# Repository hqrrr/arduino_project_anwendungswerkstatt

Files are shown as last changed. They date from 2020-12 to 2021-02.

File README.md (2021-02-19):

# Anwendungswerkstatt project climate chair 
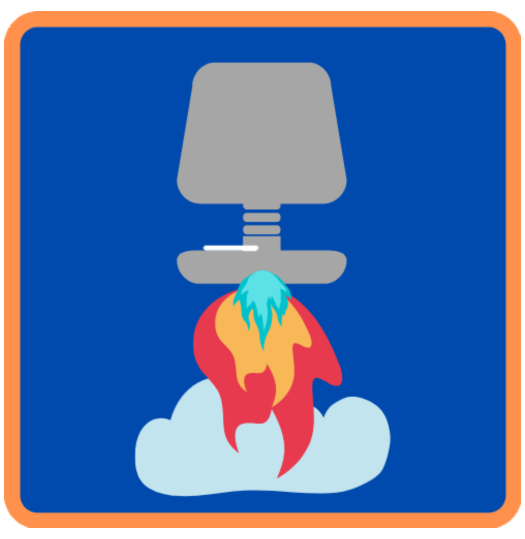
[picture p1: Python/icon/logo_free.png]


## Table of contents
1. [Diagram](#diagram)
    
    1.1 [Draft](#draft)
   
    1.2 [Circuit diagram](#circuit-diagram)

    1.3 [Sketch](#sketch)

2. [Python code](#python-code)

3. [Arduino code](#arduino-code)

    3.1 [Arduino desk (Primary)](#primary)

    3.2 [Arduino chair (Replica)](#replica)
   
4. [List of hardware](#hardware)

## 1 Diagram 

### 1.1 Draft 

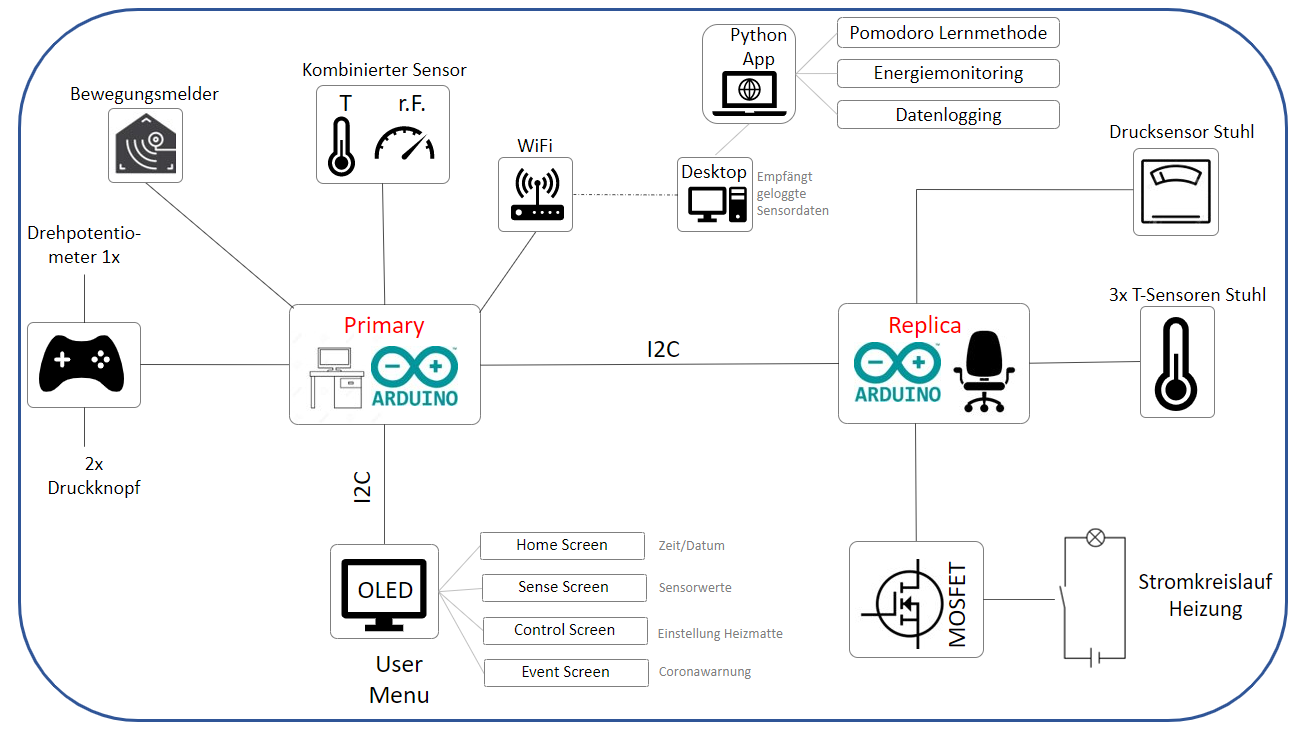
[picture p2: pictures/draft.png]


### 1.2 Circuit diagram 

#### 1.2.1 Arduino Desk (Primary) {Arduino MKR WiFi 1010}

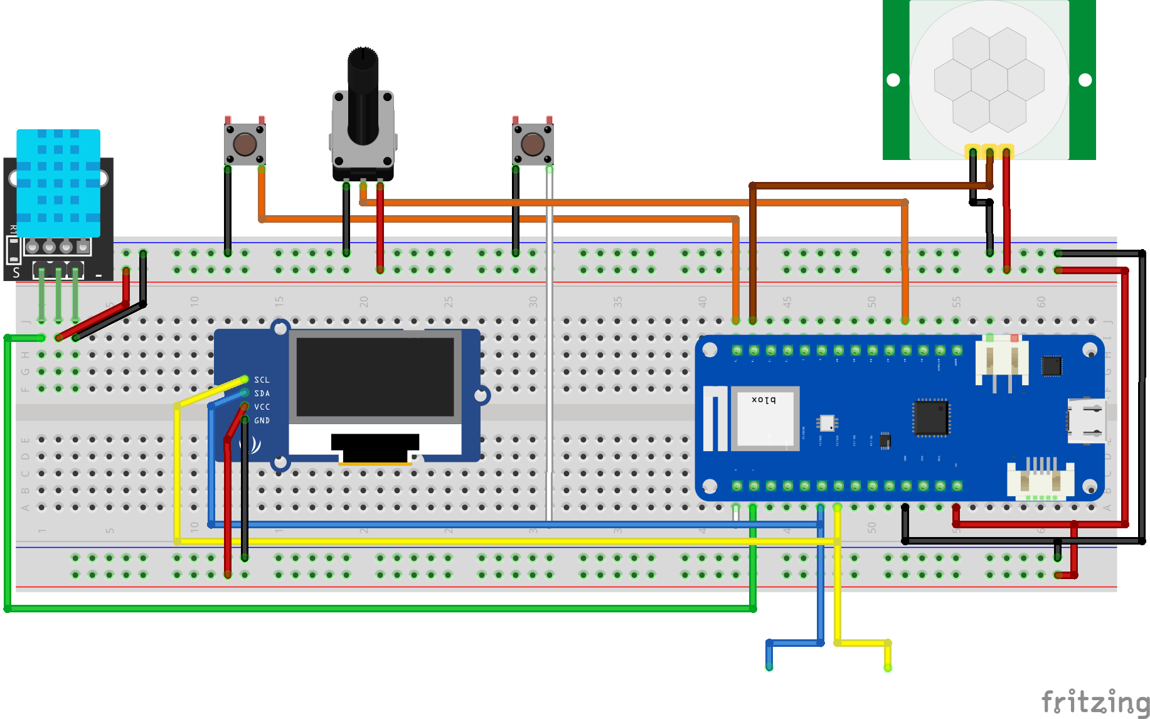
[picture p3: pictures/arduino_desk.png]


#### 1.2.2 Arduino Chair (Replica) {Arduino Nano ATmega328P (Old Bootloader)}

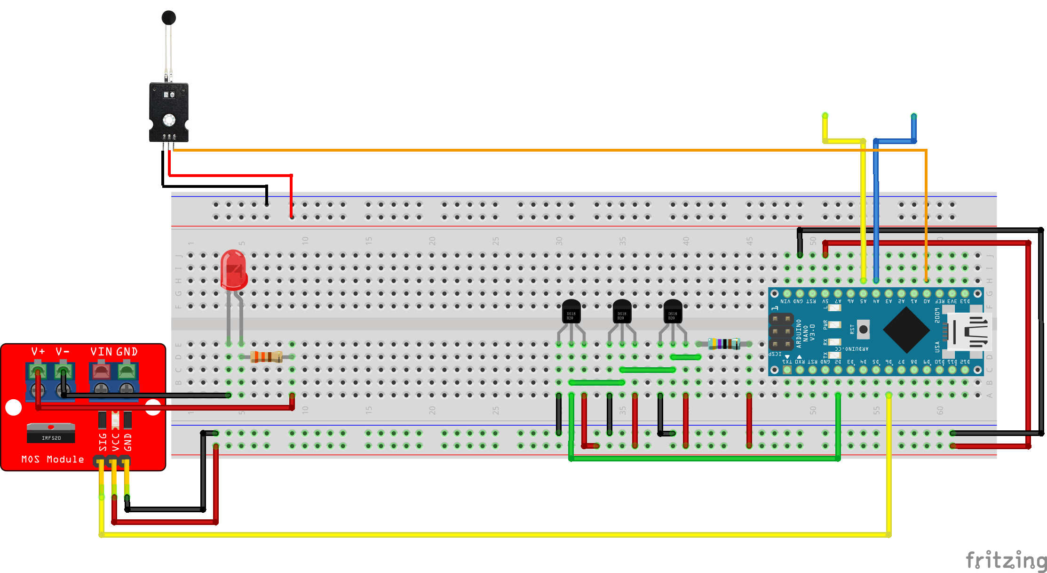
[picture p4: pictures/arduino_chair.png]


### 1.3 Sketch 

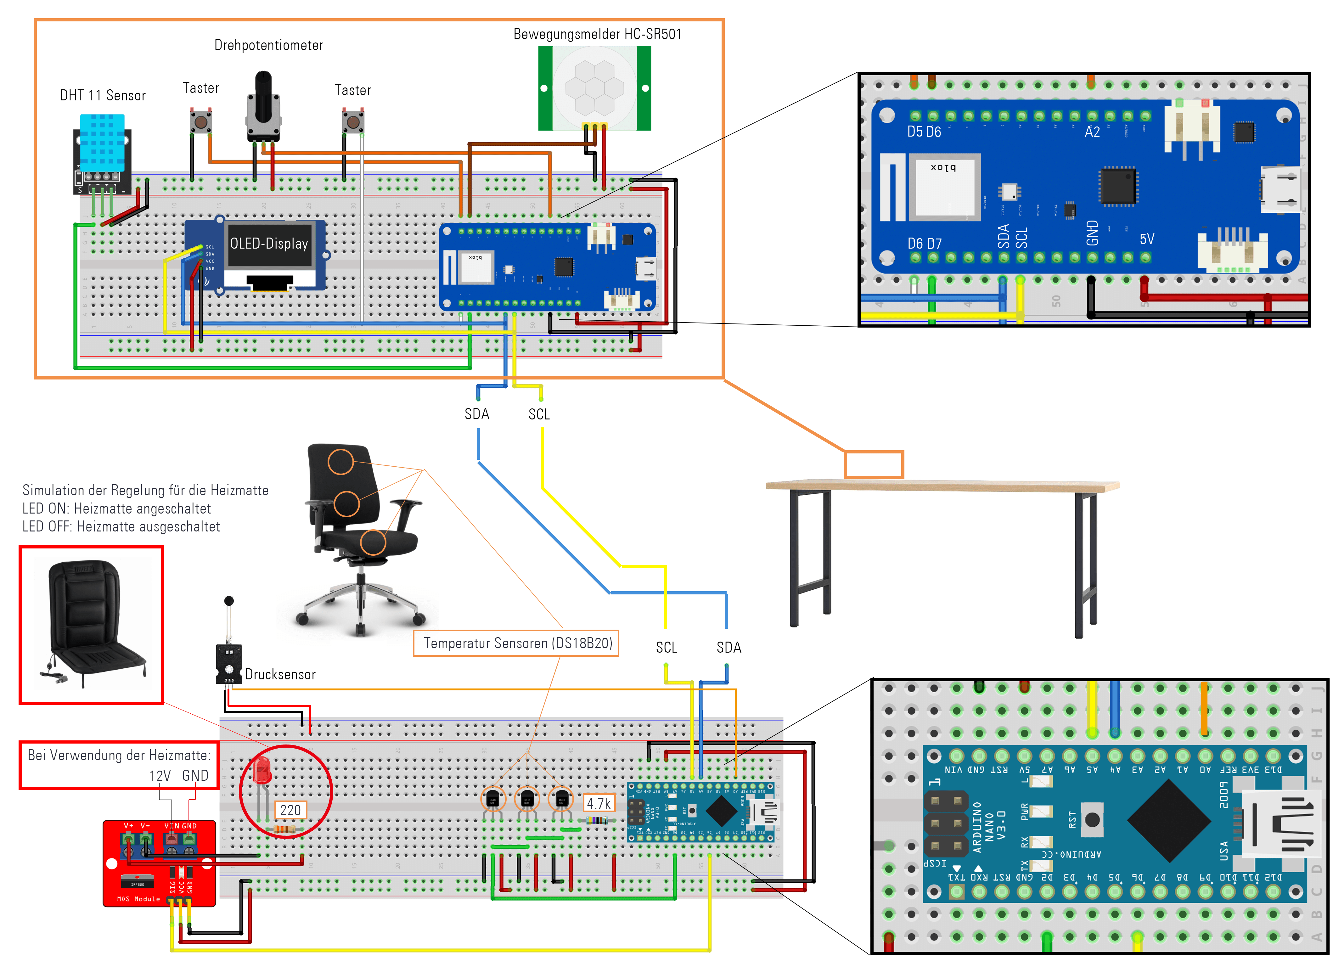
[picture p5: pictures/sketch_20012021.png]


## 2. python code 

[desktop_file.py](/Python/desktop_file.py)

settings:

[desktop.ini](/Python/desktop.ini)

Environmental:

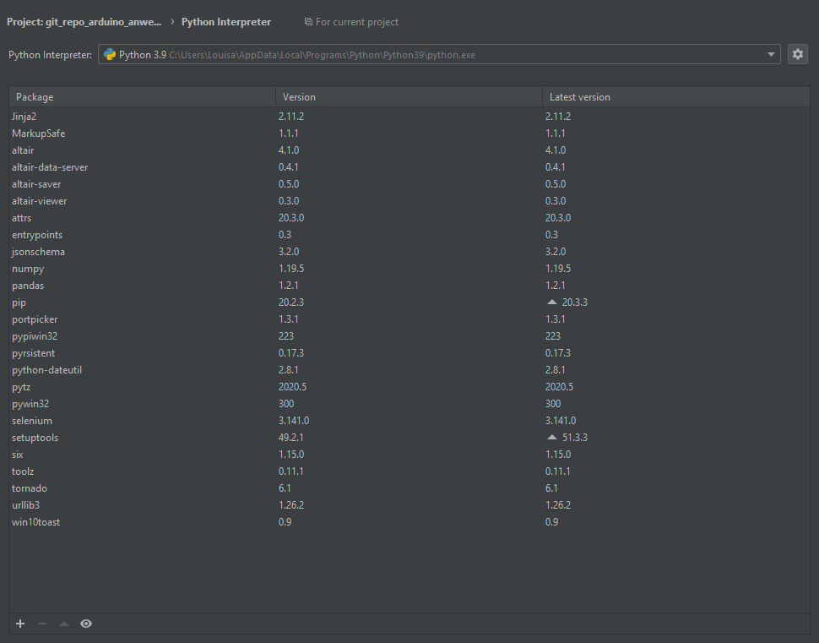
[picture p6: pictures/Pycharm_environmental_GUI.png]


## 3. Arduino code: 

### 3.1 Arduino Desk (Primary) {Arduino MKR WiFi 1010} 

[Arduino_Desk_Primary_mkr_wifi_1010.ino](/Arduino/Arduino_Desk_Primary_mkr_wifi_1010/Arduino_Desk_Primary_mkr_wifi_1010.ino)

Change WiFi username & password in:

[arduino_secrets.h](/Arduino/Arduino_Desk_Primary_mkr_wifi_1010/arduino_secrets.h)

Circuit diagram --> **1.2.1**

### 3.2 Arduino Chair (Replica) {Arduino Nano ATmega328P (Old Bootloader)} 

[Arduino_Chair_Replica_Nano.ino](/Arduino/Arduino_Chair_Replica_Nano/Arduino_Chair_Replica_Nano.ino)

Circuit diagram --> **1.2.2**

## 4. list of hardware: 

| components | name | description | Library / Software |
| --- | --- | --- | --- |
| microcontroller | Arduino Nano | ATmega 328P (old bootloader), Arduino chair. Controls sensors and actuators. | Arduino IDE |
| microcontroller with WiFi | Arduino MKR WiFi 1010 | Controls sensors and actuators. Opens servers and sends data via WiFi | Arduino IDE, WiFiNINA.h(Library), SPI.h (Library)  |
| real Time Clock | integrated in Arduino MKR WiFi 1010 | Time measurement, time update via WiFi | RTCZero.h (Library) |
| temperature and humidity sensor | DHT 11 | Measures temperature and humidity, transmits data digitally | DHT.h (Library) |
| motion sensor | HC-SR501 | passive infrared sensor | - |
| 2x button | - | An electrical connection is established by pressing a button | - |
| rotary potentiometer | - | Allows manual setting of a resistance in 1024 levels | - |
| OLED display  | SSD1306  | Display with 128 x 64 pixels, to be operated via I2C bus | Adafruit_SSD1306.h, Wire.h, Adafruit_GFX.h(Libraries)  |
| 2x Breadboard | - | - | - |
| 3x temperatur sensors | DS18B20 | A 4.7k resistor is required, see circuit diagram | OneWire.h (Library), DallasTemperature.h (Library) |
| pressure sensor | ARD SEN-PRESSURE10 | - | - |
| MOSFET | Grove MOSFET CJQ4435 | - | - |
| Heating mat | Car seat heating pad with 2 levels (12 V) | - | - |

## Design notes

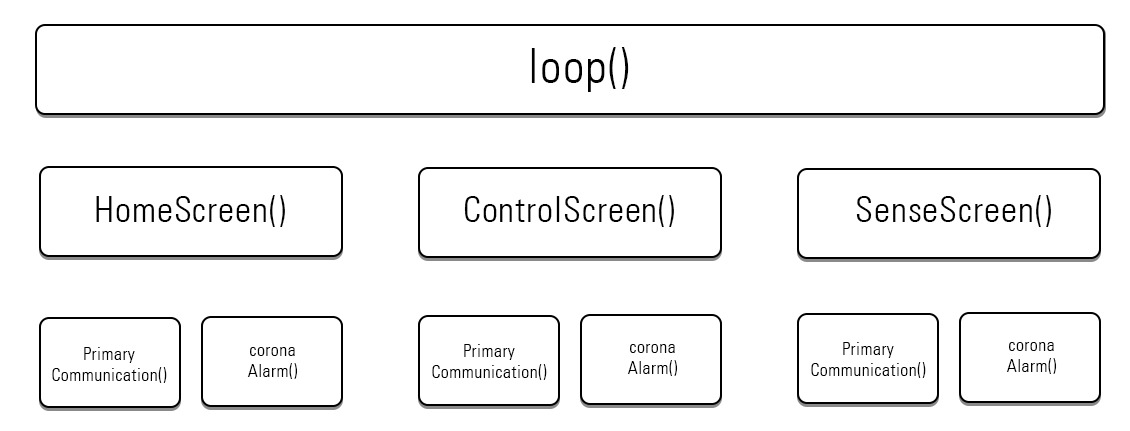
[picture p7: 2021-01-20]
pictures/structure.png

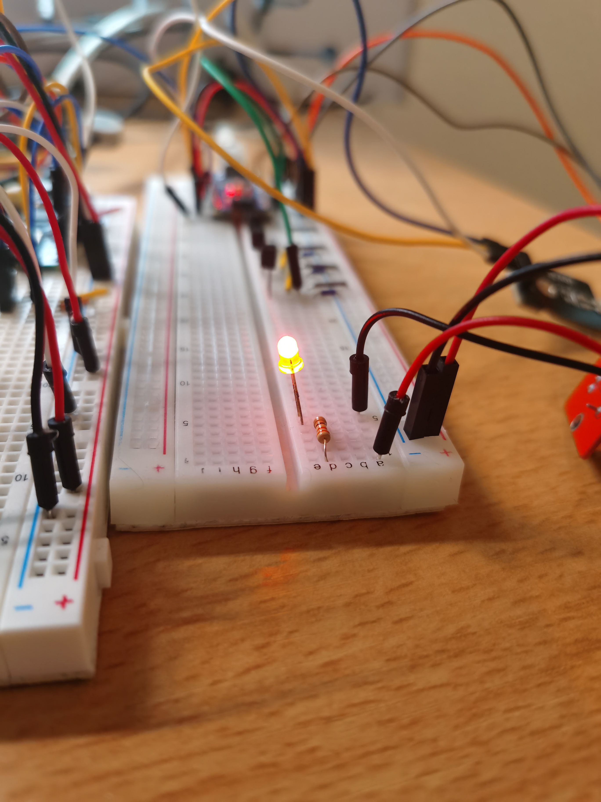
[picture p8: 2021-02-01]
pictures/LED_on.jpg

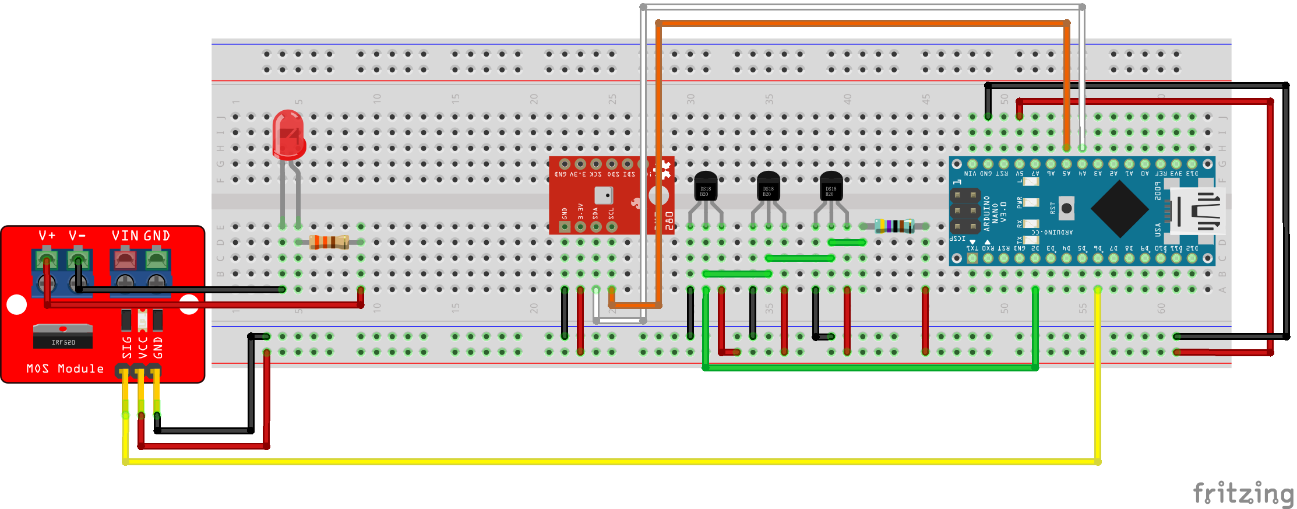
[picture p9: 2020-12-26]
pictures/arduino_dallas_bme280_mosfet.png

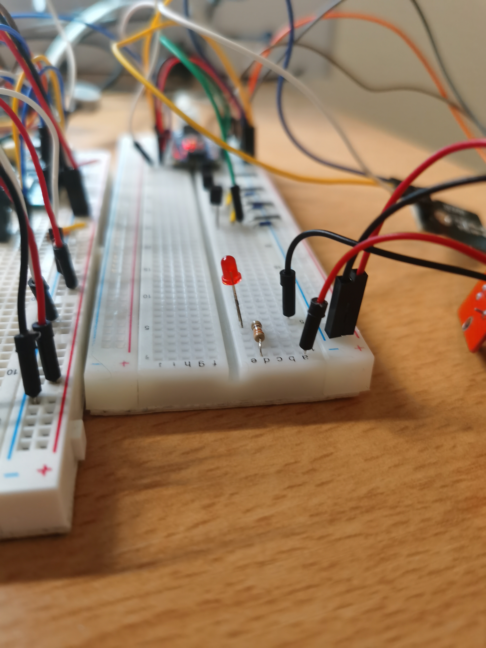
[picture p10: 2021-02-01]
pictures/LED_off.jpg

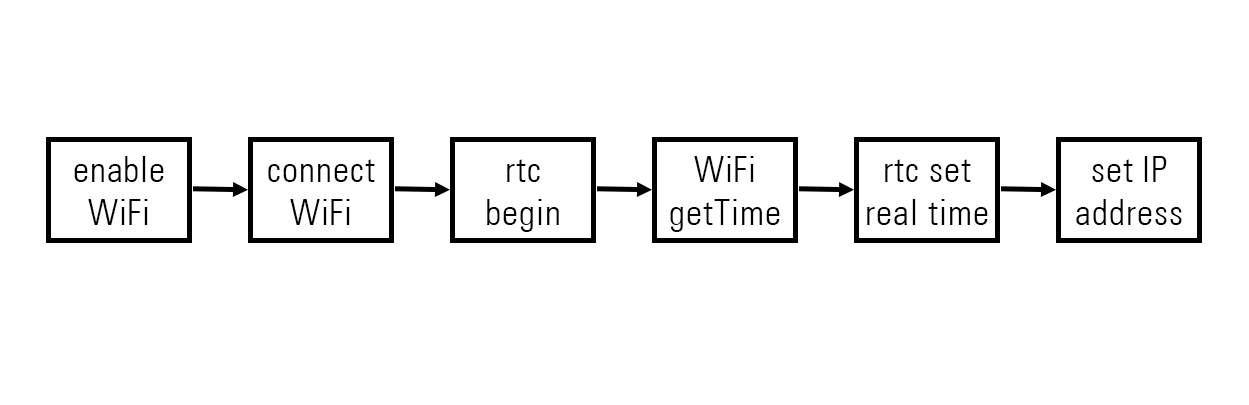
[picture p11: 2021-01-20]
pictures/process_get_time.png

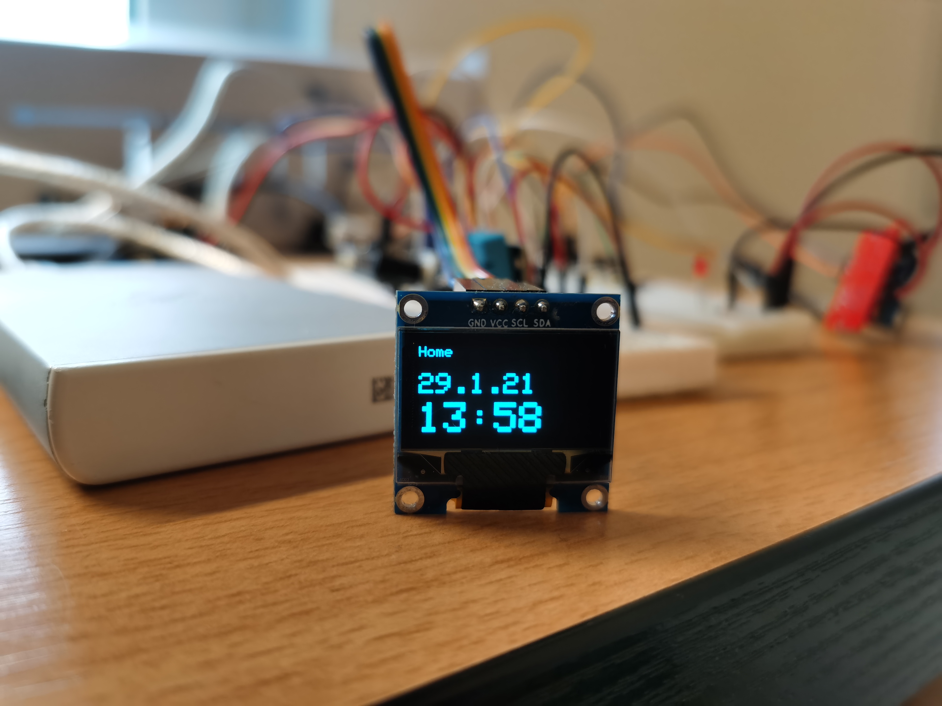
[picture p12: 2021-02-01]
pictures/homescreen.jpg

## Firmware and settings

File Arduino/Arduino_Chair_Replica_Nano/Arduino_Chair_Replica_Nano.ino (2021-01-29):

// =================================
// Arduino Nano
// Arduino 1.8.13
// Author: hqrrr
// Date of last update: Jan. 2021
// =================================

// ---------------------------
//     I2C communication
// ---------------------------
#include<Wire.h>

// ---------------------------
//  Dallas Temperature sensor
// ---------------------------
#include <OneWire.h> 
#include <DallasTemperature.h>

// Data wire is plugged into pin 2 on the Arduino 
#define ONE_WIRE_BUS 2 

// Setup a oneWire instance to communicate with any OneWire devices  
// (not just Maxim/Dallas temperature ICs) 
OneWire oneWire(ONE_WIRE_BUS); 

// Pass our oneWire reference to Dallas Temperature. 
DallasTemperature sensors(&oneWire);


// ---------------------------
//     PID controller
// ---------------------------
/*
 * by Dorian
 * Concept:
 * 1) We read the temperature (Input) in the center of the chair
 * 2) We compare the Input with Setpoint and compute Output (heaterPID.Compute())
 * 3) We translate output into Power with upper and lower limit (0-100%)
 * 4) We translate Power into a pulse to control the heater
 *
 * Reglerparameter: Kp, Ki, Kd, delay zwischen Messungen
 * (je kürzer das delay, desto schneller wächst der Integratoranteil im Regler)
 */
#include <PID_v1.h>
// PI controller
double Setpoint;  // T_set
double Input;     // T_room
double Output;    // Power
double Kp = 1, Ki = 1, Kd = 0; // Controller Parameters
// Create PID instance
PID heaterPID(&Input, &Output, &Setpoint, Kp, Ki, Kd, DIRECT);

// ---------------------------
//         Variables
// ---------------------------
// mosfet
int mosfetPin = 6;
int mosfetOn = 255; // 0 - 255
int mosfetOff = 0; // 0 - 255
int heatingOn_time;
int heatingOff_time;
// sensors
float T_chair1 = 33.3333; // DS18B20 temperature sensor on the chair
float T_chair2 = 33.3333; // DS18B20 temperature sensor on the chair
float T_chair3 = 33.3333; // DS18B20 temperature sensor on the chair
int deviceCount = 0; // count how many DS18B20 temperature sensor on the chair, by default = 0
int sitting_pressure; // pressure sensor on the chair
// settings
float T_set = 25;
// receiving
int heater_onOff;
float hum_room;
float T_room;
int is_sitting = 1; // 0:True, 1: False, by default = 1
int sit_p_setpoint = 50; // 0-1023, 0: no pressure, 1023: max. 10kg.



// the setup function runs once when you press reset or power the board
void setup() {
  // initialize digital pin LED_BUILTIN as an output.
  pinMode(mosfetPin, OUTPUT);

  // use pin A0 for pressure sensor
  pinMode(A0, INPUT);
  
  // start serial port 
  Serial.begin(9600);

  // specify the slave
  Wire.begin(8);                // join i2c bus with address #8
  // call the function when Slave receives value from master and when Master request value from Slave
  Wire.onReceive(receiveEvent); // register receive event
  Wire.onRequest(requestEvent); // register request event
  
  // Start up the library 
  sensors.begin(); 

  // PID controller
  Input = T_room;
  Setpoint = T_set;
  // Turn PID on
  heaterPID.SetMode(AUTOMATIC);
  // Adjust PID values
  heaterPID.SetTunings(Kp, Ki, Kd);

  // locate DS18B20 devices on the bus
  Serial.print("Locating devices...");
  Serial.print("Found ");
  deviceCount = sensors.getDeviceCount();
  Serial.print(deviceCount, DEC);
  Serial.println(" DS18B20 sensors.");
  Serial.println("");

}

// the loop function runs over and over again forever
void loop() {

  // Send the command to get temperatures
  sensors.requestTemperatures(); 
  // read temperature
  T_chair1 = sensors.getTempCByIndex(0);
  T_chair2 = sensors.getTempCByIndex(1);
  T_chair3 = sensors.getTempCByIndex(2);
  
  // read sitting pressure value
  sitting_pressure = analogRead(A0);
  if (sitting_pressure > sit_p_setpoint){
    is_sitting = 0;
  }
  else {
    is_sitting = 1;
  }

  // print siiting pressure between 0 and 1023 and the temperature in Celsius
  Serial.println("Sitting pressure[0-1023],Temperature[degC]_Dallas_0,Temperature[degC]_Dallas_1,Temperature[degC]_Dallas_2");
  Serial.print(sitting_pressure);
  Serial.print(",");
  Serial.print(T_chair1);
  Serial.print(",");
  Serial.print(T_chair2);
  Serial.print(",");
  Serial.println(T_chair3);

  // PID controller incl. delay
  PID_control();

}

// ---------------------------
//         Functions
// ---------------------------
void PID_control() {
  // PID controller, read Input from sensor(received from Master), compute, write Output to actuator
  Input = (T_chair1 + T_chair2 + T_chair3) / 3;  // T mean readed from chair as input
  Setpoint = T_set;
  heaterPID.Compute();
  // Set Power (Output) within 0 and 100 %
  Output = constrain(Output, 0, 100);
  //analogWrite(3, Output);
  
  // Output for serial plotter
  Serial.print("PID Input: ");
  Serial.print(Input);
  Serial.print("   ");
  Serial.print("PID Output: ");       
  Serial.print(Output);
  Serial.print("   ");
  Serial.print("PID Setpoint: ");
  Serial.println(Setpoint);  

  // Prinzip PI Regler ->
  // - On        ______         _______           ________
  // - Off _____|      |_______|       |_________|        |______
  //            /------/               /---------/
  //         heatingOn_time          heatingOff_time
  // z.B. PID Output = 0 -> heatingOn_time = 0 und heatingOff_time = 5000 (Periode: 5 sec.)
  //      PID Output = 100 -> heatingOn_time = 5000 und heatingOff_time = 0.
  
  heatingOn_time = 5000 * Output / 100;
  heatingOff_time = 5000 - heatingOn_time;

  if (T_chair1 < T_set && T_chair2 < T_set && T_chair3 < T_set && is_sitting == 0 && heater_onOff == 0){
    
    analogWrite(mosfetPin, mosfetOn); // Heizmatte anschalten
    delay(heatingOn_time); // die Zeit ist abhängig von PID Output
    analogWrite(mosfetPin, mosfetOff);
    delay(heatingOff_time);
  }
  else {
    analogWrite(mosfetPin, mosfetOff);
    delay(5000);
  }
}


void requestEvent() {
  String T00_is_chair_Str = String(T_chair1, DEC).substring(0,4);
  String T01_is_chair_Str = String(T_chair2, DEC).substring(0,4);
  String T02_is_chair_Str = String(T_chair3, DEC).substring(0,4);
  String is_sitting_Str = String(is_sitting, DEC).substring(0,1);
  String PID_Output_Str = String(Output, DEC).substring(0,4);
  Wire.write(T00_is_chair_Str.c_str());        // respond with message of 4 bytes as expected by master
  Serial.println("T00_chair = " + String(T_chair1));
  Wire.write(T01_is_chair_Str.c_str());        // respond with message of 4 bytes as expected by master
  Serial.println("T01_chair = " + String(T_chair2));
  Wire.write(T02_is_chair_Str.c_str());        // respond with message of 4 bytes as expected by master
  Serial.println("T02_chair = " + String(T_chair3));
  Wire.write(is_sitting_Str.c_str());        // respond with message of 4 bytes as expected by master
  Serial.println("is_sitting = " + String(is_sitting));
  Wire.write(PID_Output_Str.c_str());        // respond with message of 1 bytes as expected by master
  Serial.println("PID Output = " + String(Output));
}

void receiveEvent(int howMany) {

  char data_received[31];
  int i=0;

  Serial.print("Wire.available() = ");
  Serial.println(Wire.available());
  
  while (0 < Wire.available()) {            // loop through all bytes
    data_received[i] = Wire.read();         // receive byte as a character
    i++;
  }

  // Handling the received data
  String data = (String)data_received;

  Serial.println("Data_received = ");
  Serial.println(data_received);
  
  if (data.substring(0,1) == "0") {heater_onOff = 0;}
  else if (data.substring(0,1) == "1") {heater_onOff = 1;}
  else {heater_onOff = 1; Serial.println("heater_onOff ERROR: Wrong format");}
  
  T_set = data.substring(1,3).toFloat();
  hum_room = data.substring(3,7).toFloat();
  T_room = data.substring(7,11).toFloat();

  Serial.print("heater_onOff: ");
  Serial.println(heater_onOff);
  Serial.print("T_set: ");
  Serial.println(T_set);
  Serial.print("humidity room: ");
  Serial.println(hum_room);
  Serial.print("temperature room: ");
  Serial.println(T_room);
  
}

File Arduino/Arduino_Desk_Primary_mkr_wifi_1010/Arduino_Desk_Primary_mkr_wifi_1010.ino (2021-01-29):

// =================================
// Arduino MKR wifi 1010
// Arduino 1.8.13
// Author: hqrrr
// Date of last update: Jan. 2021
// =================================

#include<Wire.h>                //for I2C communication

//#include <DS3231.h>                //for Real Time Clock
#include <RTCZero.h>
// Declaration Real Time Clock
//RTClib RTC;                        // Initialize real time clock
RTCZero rtc;

const int GMT = 1; //change this to adapt it to your time zone, Germany: GMT + 1

// ---------------------------
//   SSD1306 Display (I2C)
// ---------------------------
#include <Adafruit_GFX.h>          //Include Libraries
#include <Adafruit_SSD1306.h>      //for OLED Display
// Declaration for SSD1306 Display (I2C)
#define SCREEN_WIDTH 128           //pixels display width
#define SCREEN_HEIGHT 64           //pixels display height
#define OLED_RESET -1              
Adafruit_SSD1306 display(SCREEN_WIDTH, SCREEN_HEIGHT, &Wire, OLED_RESET);

// ---------------------------
//      DHT 11 sensor
// ---------------------------
#include <DHT.h>
//Declaration Temp/Hum-Sensor
#define DHTPIN 7                    // sensor pin number 7 (Digital Pin)
#define DHTTYPE DHT11               // sensor type: DHT 11 (DHT22 also possible)

//Declaration DHT-Sensor
DHT dht(DHTPIN, DHTTYPE);          // Initialize DHT sensor for normal 16mhz Arduino

// ---------------------------
//    PIR sensor hc-sr-501
// ---------------------------
#include<Wire.h>

// ---------------------------
//        Wifi Module
// ---------------------------
#include <SPI.h>
#include <WiFiNINA.h>
#include "arduino_secrets.h"

// WiFi ID & PW -> arduino_secrets.h
char ssid[] = SECRET_SSID;        // your network SSID (name)
char pass[] = SECRET_PASS;    // your network password (use for WPA, or use as key for WEP)
int keyIndex = 0;                 // your network key Index number (needed only for WEP)

int status = WL_IDLE_STATUS;     // the Wifi radio's status
WiFiServer server(80);            //server socket


// ---------------------------
//         Variables
// ---------------------------

// Motion Sensor
const int PIN_TO_SENSOR = 4;   // the pin that OUTPUT pin of sensor is connected to
int pinStateCurrent   = LOW; // current state of pin
int pinStatePrevious  = LOW; // previous state of pin

// Variables for Data-Logging and Controlling
// Sending to Slave
char heater_onOff = '0';      // default setting after turning on device, 0: on, 1: off
float T_set = 30;          // default setting after turning on device
float hum_room;       
float T_room;

// Receiving from Slave
float T00_is_chair;   // temperature
float T01_is_chair;
float T02_is_chair;
int is_sitting = 1;   // 0: true, 1:false, by default = 1
float PID_Output;
// bool is_sitting;  // evtl. rauslassen

// Global Variables for practical reasons
int timerI2C=0; //to store the last second Information has been sent to Slave

// the setup function runs once when you press reset or power the board
void setup() {
  // start serial port 
  Serial.begin(9600); 

  // Begins I2C communication at pin (A4,A5)
  Wire.begin();

  // start read data from dht sensor
  dht.begin();
  
  enable_WiFi();
  connect_WiFi();

  // real time clock
  rtc.begin();
  unsigned long epoch;
  int numberOfTries = 0, maxTries = 15; // try maxTries times to get real time from server.
  do {
    epoch = WiFi.getTime();
    numberOfTries++;
    // if NTP unreachable, try again after 2 sec.
    if(epoch == 0){
      Serial.print("WiFi.getTime try again...");
      Serial.print(numberOfTries);
      Serial.print(" / ");
      Serial.println(maxTries);
      delay(2000);
    };
  }
  while ((epoch == 0) && (numberOfTries < maxTries));
  if (numberOfTries == maxTries) {
    Serial.print("NTP unreachable!!");
    //while (1);
  }
  else {
    Serial.print("Epoch received: ");
    Serial.println(epoch);
    rtc.setEpoch(epoch);
    Serial.println();
  }

  // setup IP address - 192.168.0.99
  WiFi.config(IPAddress(192, 168, 0, 99));
  
  server.begin();
  
  // you're connected now, so print out the WiFi data:
  Serial.println("You're connected to the network");
  Serial.println("----------------------------------------");
  printWifiStatus();
  Serial.println("----------------------------------------");

  // button
  pinMode(6, INPUT_PULLUP);
  pinMode(5, INPUT_PULLUP);
  
  // Error message
  if(!display.begin(SSD1306_SWITCHCAPVCC, 0x3C)) {
    Serial.println(F("SSD1306 allocation failed"));
    for(;;);
  }

  // serial plotter labels
  Serial.println("Temperature[degC],Humidity[%],T00_is_chair[degC],T01_is_chair[degC],T02_is_chair[degC]");
  
}

// the loop function runs over and over again forever
void loop() {

  HomeScreen();
  ControlScreen();
  SenseScreen();
  
}
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

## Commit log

2020-11-13 add circuit diagram
    [arduino.fzz]
2020-11-13 add multiple DS18B20 sensors
2020-11-13 update circuit diagram
    [arduino.fzz]
2020-11-19 add Arduino MKR WiFi 1010 board
2020-11-29 Drucksensor
    Anleitung https://joy-it.net/files/files/Produkte/SEN-Pressure10/SEN-Pressure-Anleitung-20201020.pdf
2020-12-03 Create OLED_Menu
    OLED-Funktionen und das User Interface
2020-12-26 update: add mosfet
2020-12-26 add sketch
    [arduino_dallas_bme280_mosfet.fzz]
2021-01-03 Create PI_Control
    Short sketch to show how the PID-Library works
2021-01-12 fix data type of is_sitting, change from float to int
    [Arduino_nano_mkr_wifi_1010_I2C_connection_Master_mkr_1010.ino]
2021-01-12 fix issue: getTime() doesnt work with fixed IP
    1. getTime() before assign a fixed ip address -> issue solved
    2. update time zone -> DE GMT +1
    [Arduino_nano_mkr_wifi_1010_I2C_connection_Master_mkr_1010.ino]
2021-01-12 update Mosfet setting
2021-01-12 fix error: PID Input
    changed PID Input from T_room to the mean value of T00/01/02 from chair
    [Arduino_nano_mkr_wifi_1010_I2C_connection_Slave_Nano.ino]
2021-01-12 Release version of Arduino Code
    Move all old useless code to archive
2021-01-20 Update Pictures
    [arduino_chair.fzz, arduino_desk.fzz]
2021-01-21 adding desktop climate chair control
    - datalogging climate sensor data in csv file
    - every 5 seconds new data
    - logging module with log files for debugging purpose
    - html charts are generated after end of day with altair
    - ini file added which holds all limits/variables set by customer
    - icon and fancy gif added for fun
    [data_2021-01-19.csv]
2021-01-23 added notifcations revamped folder structur corrected spelling mistakes added gif at the beginning added all possible logos and icons in png, ico and with or without background
    [data_2021-01-19.csv, data_2021-01-23.csv]
2021-02-01 fixed pictures error: no pressure sensor
